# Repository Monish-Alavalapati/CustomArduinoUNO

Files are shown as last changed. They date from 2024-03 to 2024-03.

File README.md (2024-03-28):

# CustomArduinoUNO
Made a custom arduino PCB design which is cost effective and has optimized power management
## Overview

This repository contains the necessary files for the custom Arduino board designed using KiCad software. It includes the PCB design, Gerber files, and schematic layout.

## Files Included

1. **PCB Design File**: This file contains the design of the custom Arduino board. It's in KiCad format (.kicad_pcb) and can be opened using KiCad software for further modification.

2. **Gerber Files**: Gerber files are industry-standard files used for PCB manufacturing. These files contain all the necessary information for the fabrication of the PCB. They include layers such as copper traces, solder mask, and silkscreen.

3. **Schematic Layout**: The schematic layout of the custom Arduino board is provided in KiCad format (.sch). It shows the connections and components used in the design.

## How to Use

### Viewing the PCB Design and Schematic Layout

1. Install KiCad: If you haven't already, download and install KiCad from [KiCad's official website](https://www.kicad.org/).

2. Open Files:
   - To view the PCB design, open the `.kicad_pcb` file using KiCad's PCB Layout Editor.
   - To view the schematic layout, open the `.sch` file using KiCad's Schematic Editor.

### Manufacturing the PCB

1. Gerber Files: These are the files you'll need to submit to your PCB manufacturer. Most manufacturers have instructions on their websites for uploading Gerber files.

2. Verify Design: Before sending the files for manufacturing, double-check the design to ensure all connections and components are as intended.

3. Fabrication: Upload the Gerber files to your chosen PCB manufacturer and follow their instructions for fabrication. Make sure to specify any special requirements or preferences.

### Customization

Feel free to modify the design according to your requirements. You can use KiCad to make changes to the PCB layout or schematic as needed. Remember to update the Gerber files if significant changes are made before fabrication.

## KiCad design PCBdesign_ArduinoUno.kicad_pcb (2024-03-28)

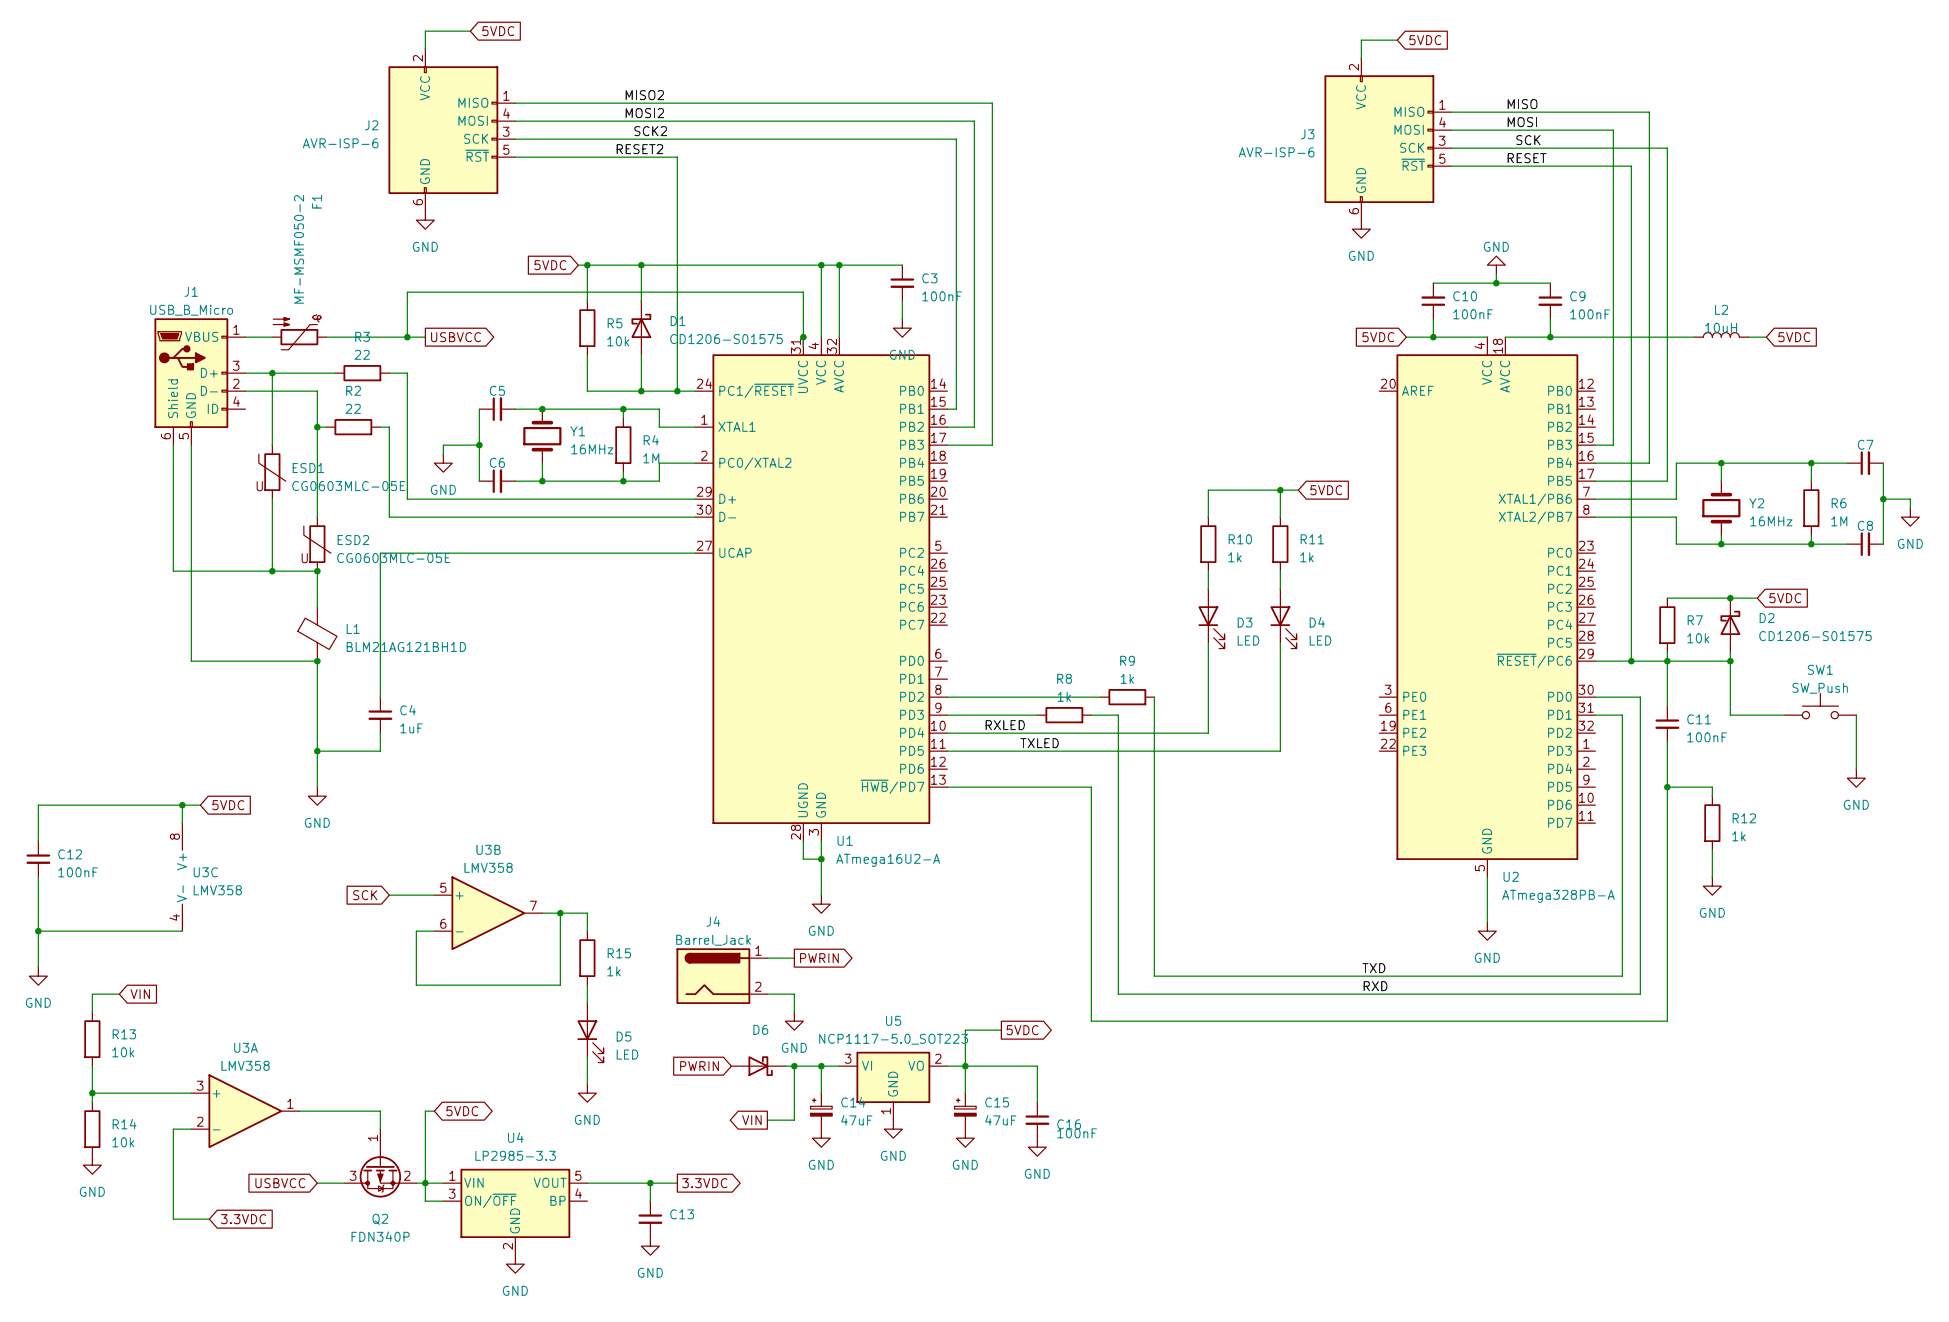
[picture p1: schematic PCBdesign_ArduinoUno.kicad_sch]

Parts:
C3, C9, C10, C11, C12, C16: 100nF; C_0603_1608Metric
C4: 1uF; C_0603_1608Metric
C5, C6, C7, C8, C13: C_0603_1608Metric
C14, C15: 47uF; C_Elec_6.3x5.8
D1, D2: CD1206-S01575; D_1206_3216Metric
D3, D4, D5: LED; LED_0603_1608Metric
D6: D_1206_3216Metric
ESD1, ESD2: CG0603MLC-05E; R_0603_1608Metric
F1: MF-MSMF050-2; R_1812_4532Metric
J1: USB_B_Micro; USB_Micro-B_Amphenol_10103594-0001LF_Horizontal
J2, J3: AVR-ISP-6; PinHeader_2x03_P2.54mm_Vertical_SMD
J4: Barrel_Jack; BarrelJack_SwitchcraftConxall_RAPC10U_Horizontal
L1: BLM21AG121BH1D; L_0805_2012Metric
L2: 10uH; L_0603_1608Metric
Q2: FDN340P; SOT-23
R2, R3: 22; R_0603_1608Metric
R4, R6: 1M; R_0603_1608Metric
R5, R7, R13, R14: 10k; R_0603_1608Metric
R8, R9, R10, R11, R12, R15: 1k; R_0603_1608Metric
SW1: SW_Push; SW_Tactile_SPST_NO_Straight_CK_PTS636Sx25SMTRLFS
U1: ATmega16U2-A; TQFP-32_7x7mm_P0.8mm
U2: ATmega328PB-A; TQFP-32_7x7mm_P0.8mm
U3: LMV358; VSSOP-8_3.0x3.0mm_P0.65mm
U4: LP2985-3.3; SOT-23-5
U5: NCP1117-5.0_SOT223; SOT-223-3_TabPin2
Y1, Y2: 16MHz; Crystal_SMD_Abracon_ABM3-2Pin_5.0x3.2mm

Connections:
3.3VDC: C13.1, U3.2 (-), U4.5 (VOUT)
5VDC: C3.1, C10.1, C12.1, C15.1, C16.1, D1.1 (K), D2.1 (K), J2.2 (VCC), J3.2 (VCC), L2.2, Q2.2 (S), R5.1, R7.1, R10.1, R11.1, U1.4 (VCC), U1.32 (AVCC), U2.4 (VCC), U3.8 (V+), U4.1 (VIN), U4.3 (ON/~OFF), U5.2 (VO)
/MISO: J3.1 (MISO), U2.16 (PB4)
/MISO2: J2.1 (MISO), U1.17 (PB3)
/MOSI: J3.4 (MOSI), U2.15 (PB3)
/MOSI2: J2.4 (MOSI), U1.16 (PB2)
/RESET: C11.1, D2.2 (A), J3.5 (~RST), R7.2, SW1.1, U2.29 (~RESET/PC6)
/RESET2: D1.2 (A), J2.5 (~RST), R5.2, U1.24 (PC1/~RESET)
/RXD: R8.2, U2.30 (PD0)
/RXLED: D3.1 (K), U1.10 (PD4)
/SCK2: J2.3 (SCK), U1.15 (PB1)
/TXD: R9.2, U2.31 (PD1)
/TXLED: D4.1 (K), U1.11 (PD5)
GND: C3.2, C4.2, C5.1, C6.1, C7.2, C8.2, C9.1, C10.2, C12.2, C13.2, C14.2, C15.2, C16.2, D5.1 (K), J1.5 (GND), J2.6 (GND), J3.6 (GND), J4.2, L1.2, R12.2, R14.2, SW1.2, U1.3 (GND), U1.28 (UGND), U2.5 (GND), U2.21 (GND), U3.4 (V-), U4.2 (GND), U5.1 (GND)
unnamed: D3.2 (A), R10.2
unnamed: D4.2 (A), R11.2
unnamed: D5.2 (A), R15.2
unnamed: ESD1.1, J1.3 (D+), R3.1
unnamed: ESD2.1, J1.2 (D-), R2.1
unnamed: ESD1.2, ESD2.2, J1.6 (Shield), L1.1
unnamed: F1.2, J1.1 (VBUS)
unnamed: Q2.1 (G), U3.1
unnamed: R3.2, U1.29 (D+)
unnamed: R2.2, U1.30 (D-)
unnamed: C6.2, R4.2, U1.2 (PC0/XTAL2), Y1.1
unnamed: R9.1, U1.8 (PD2)
unnamed: R8.1, U1.9 (PD3)
unnamed: C4.1, U1.27 (UCAP)
unnamed: C5.2, R4.1, U1.1 (XTAL1), Y1.2
unnamed: C11.2, R12.1, U1.13 (~HWB/PD7)
unnamed: C9.2, L2.1, U2.18 (AVCC)
unnamed: C7.1, R6.1, U2.7 (XTAL1/PB6), Y2.2
unnamed: C8.1, R6.2, U2.8 (XTAL2/PB7), Y2.1
unnamed: R13.2, R14.1, U3.3 (+)
unnamed: R15.1, U3.6 (-), U3.7
PWRIN: D6.2 (A), J4.1
SCK: J3.3 (SCK), U2.17 (PB5), U3.5 (+)
USBVCC: F1.1, Q2.3 (D), U1.31 (UVCC)
VIN: C14.1, D6.1 (K), R13.1, U5.3 (VI)

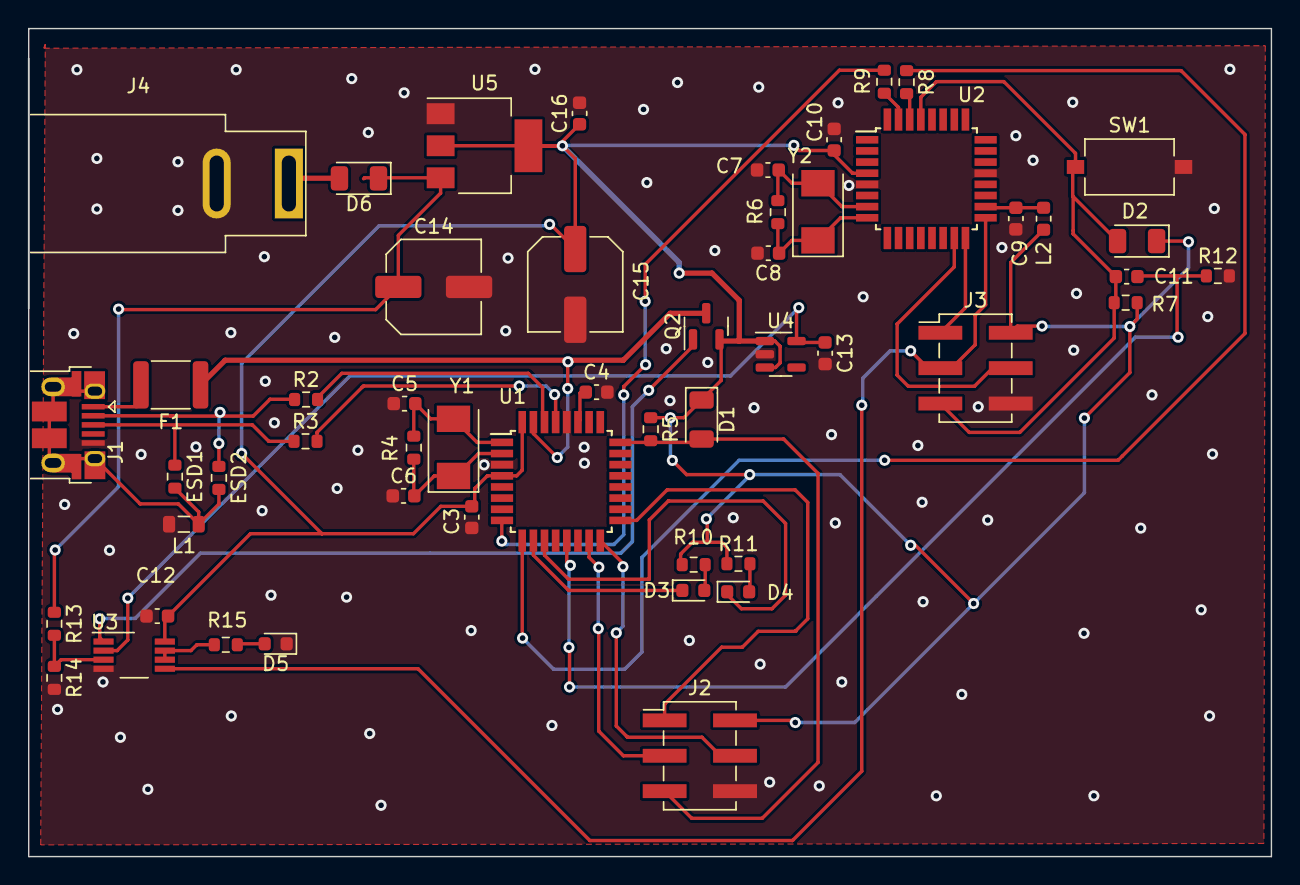
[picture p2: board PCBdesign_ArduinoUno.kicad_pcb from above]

Board: 2 copper layers, 89.2 x 59.4 mm, 52 parts (0 on the bottom side), 39 nets.
